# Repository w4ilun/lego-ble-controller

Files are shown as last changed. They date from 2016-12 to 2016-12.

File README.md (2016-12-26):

##4-channel Bluetooth LE controller for Lego Power Functions w/ Web Bluetooth

First attempt at making a Lego BLE contoller.

* PCB Design and Fabrication - EasyEDA
* Firmware - Arduino
* Remote Control App - Web Bluetooth APIs

###Top Layer
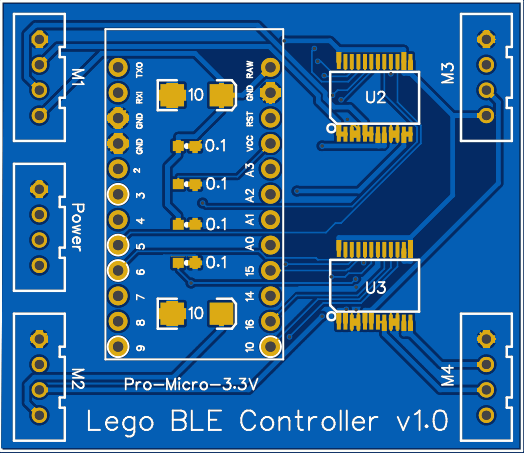
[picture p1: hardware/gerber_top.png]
Top Layer


###Bottom Layer
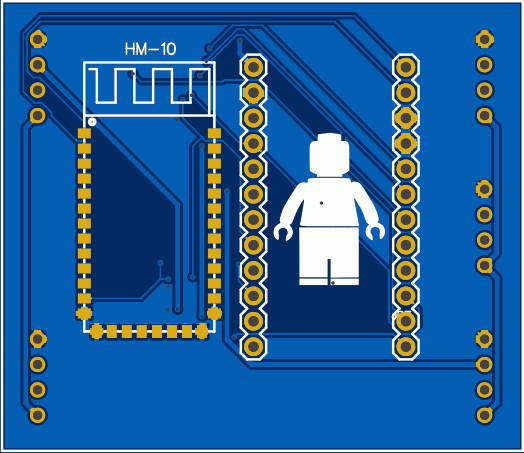
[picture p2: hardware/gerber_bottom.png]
Bottom Layer


###Components
* 1 x Arduino Pro Micro module
* 1 x HM-10 Bluetooth LE module
* 2 x TB6612FNG Motor Controller IC - U2 & U3
* 2 x Tantalum Capacitor 10uF 25V
* 4 x Ceramic Capacitor 0.1uF 25V
* 5 x JST-XH 4 Pin Connectors Male/Female pairs
* 5 x Lego Power Functions Extension Wire

###Remote Control App
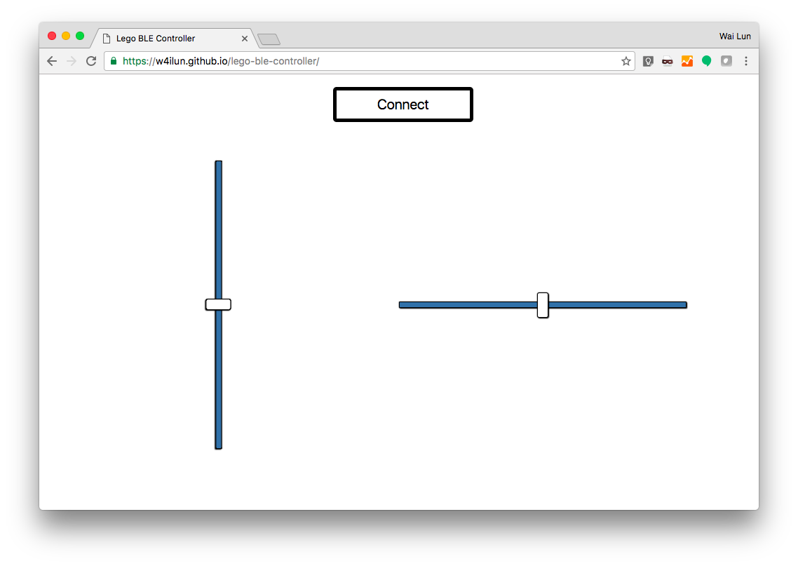
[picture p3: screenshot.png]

* Uses the Web Bluetooth API in Chrome to connect and control the board
* To use, first enable Web Bluetooth in your Chrome browser (e.g. chrome://flags )
* Go to https://w4ilun.github.io/lego-ble-controller on your phone or desktop and click connect
* Feel free to customize the UI with additional controls and adding the remaining channels

##Control Protocol
* The acceptable range for each channel are integers between -255 and 255
* (-) negative values will reverse the motor/servo direction
* Encoding Scheme: **m1val**#**m2val**#**m3val**#**m4val** E.g. 100#255#-128#30

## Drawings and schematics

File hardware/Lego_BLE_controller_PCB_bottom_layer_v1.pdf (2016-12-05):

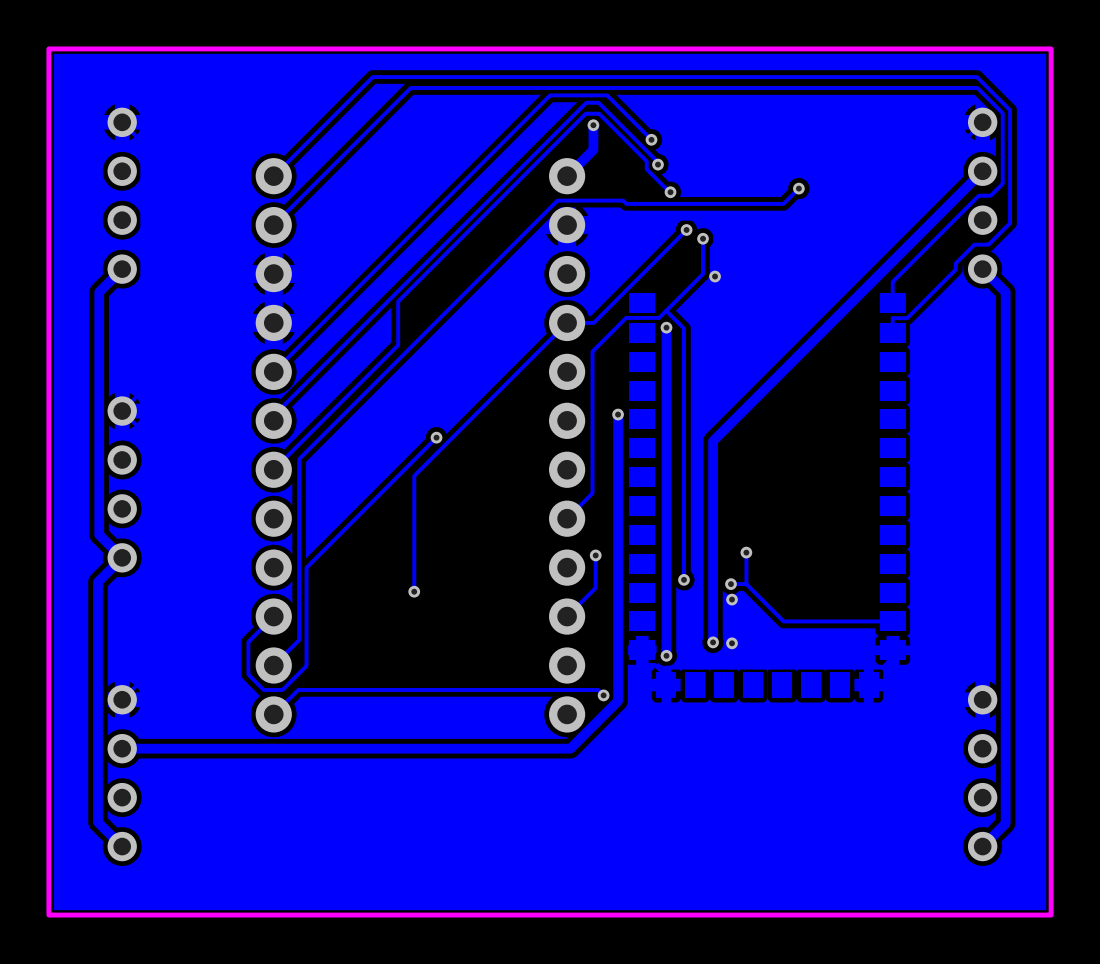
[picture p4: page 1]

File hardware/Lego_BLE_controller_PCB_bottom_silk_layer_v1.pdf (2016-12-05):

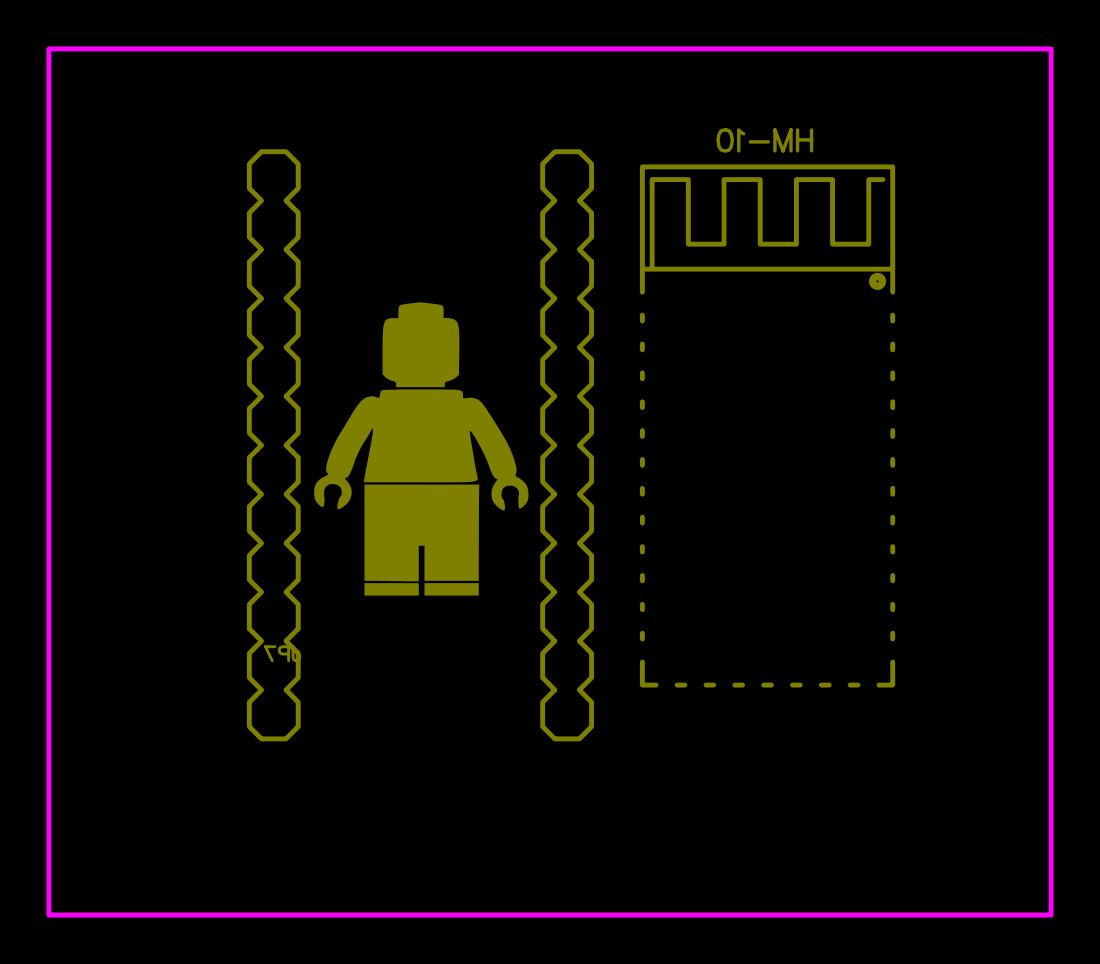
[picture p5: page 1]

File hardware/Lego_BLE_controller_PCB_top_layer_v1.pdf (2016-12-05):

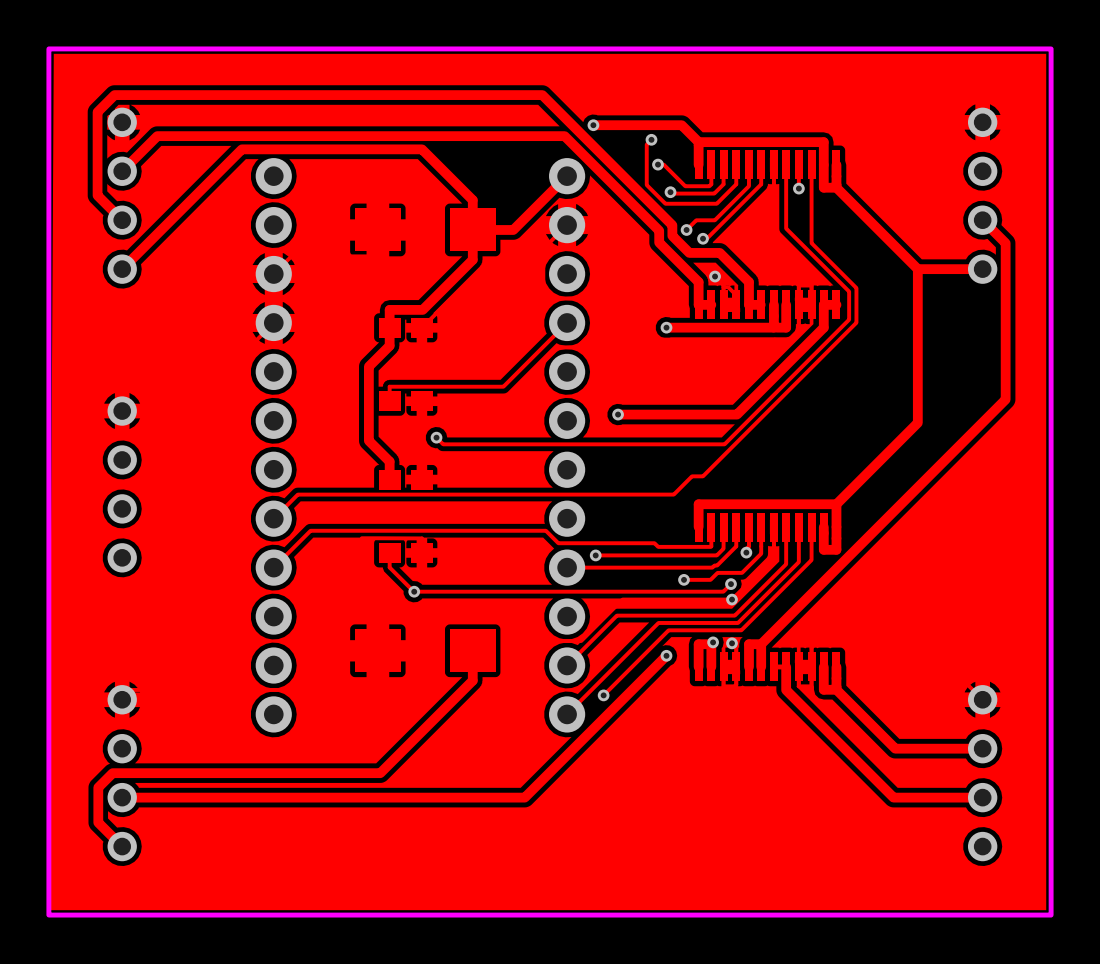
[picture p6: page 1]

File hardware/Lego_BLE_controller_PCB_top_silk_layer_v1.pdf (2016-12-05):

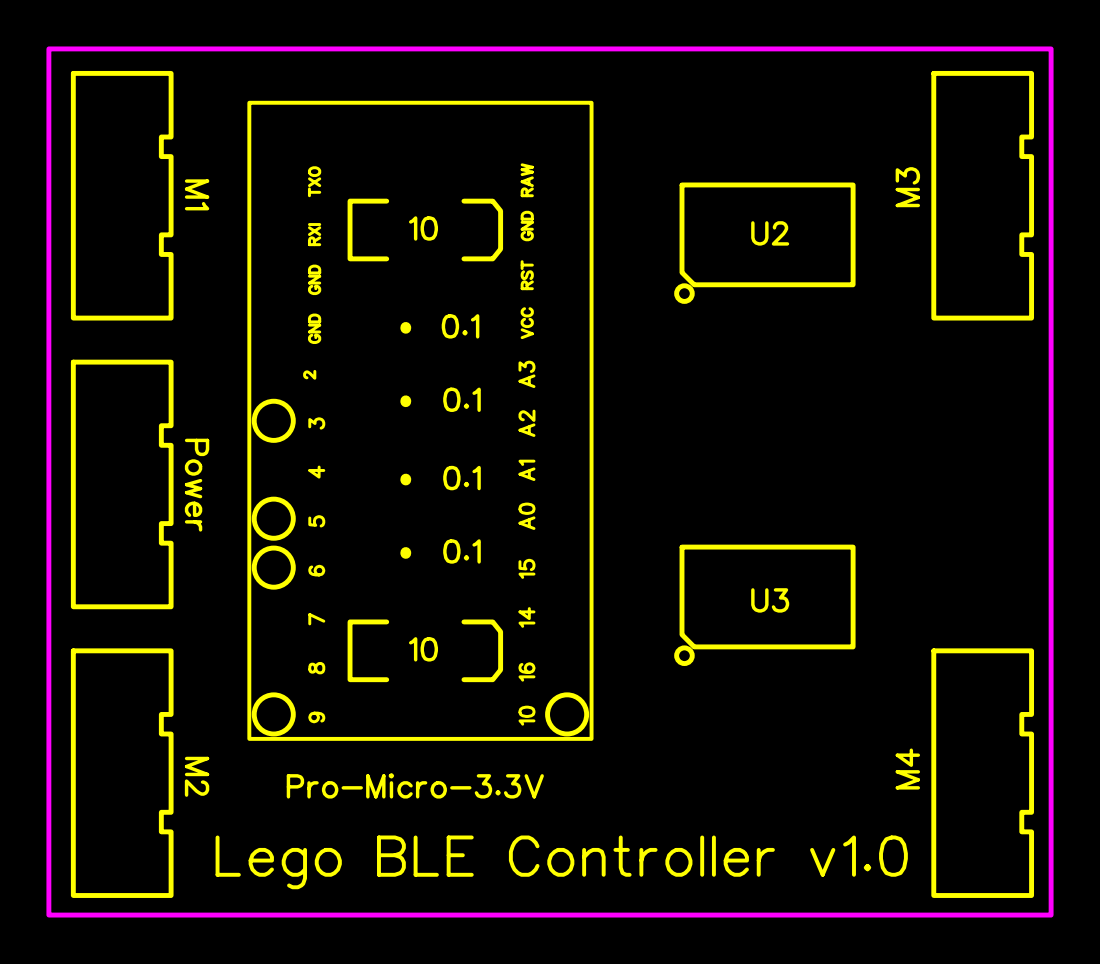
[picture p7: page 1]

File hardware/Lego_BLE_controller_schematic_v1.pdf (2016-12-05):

## VCC

V3.3

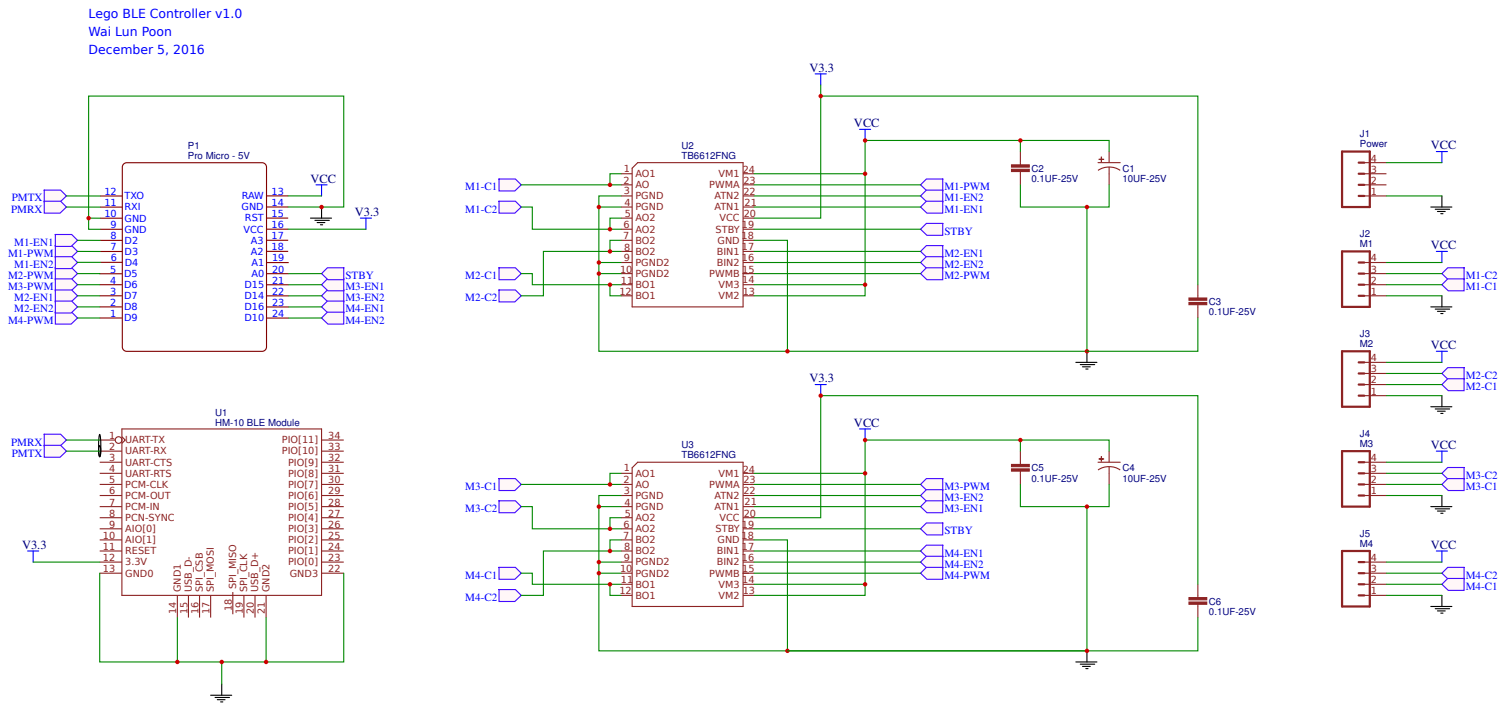
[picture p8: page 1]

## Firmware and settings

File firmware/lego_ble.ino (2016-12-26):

#define INPUT_SIZE 30 //input buffer size

//motor channel struct
struct Channel {
    int en1;
    int en2;
    int pwm;
    int value;
};

Channel m1 = { 2 , 4 , 3 , 0 }; // en1 , en2 , pwm , value
Channel m2 = { 7 , 8 , 5 , 0 };
Channel m3 = { 15 , 14 , 6 , 0 };
Channel m4 = { 16 , 10 , 9 , 0 };

//standby, pin must be HIGH to enable motor drivers
int standby = 18;

//serial input buffer
char inputBuffer[INPUT_SIZE + 1];

void setup() {
    
    pinMode(m1.en1, OUTPUT);
    pinMode(m1.en2, OUTPUT);
    pinMode(m1.pwm, OUTPUT);
    pinMode(m2.en1, OUTPUT);
    pinMode(m2.en2, OUTPUT);
    pinMode(m2.pwm, OUTPUT);
    pinMode(m3.en1, OUTPUT);
    pinMode(m3.en2, OUTPUT);
    pinMode(m3.pwm, OUTPUT);
    pinMode(m4.en1, OUTPUT);
    pinMode(m4.en2, OUTPUT);
    pinMode(m4.pwm, OUTPUT);
    pinMode(standby, OUTPUT);

    digitalWrite(standby, HIGH);

    Serial1.begin(115200); //hardware Serial1 - default HM-10 baud rate is 9600, mine was changed e.g. AT+BAUD
    Serial1.setTimeout(10);
    while(!Serial1);
}

void loop() {
    if(Serial1.available() > 0){
        byte size = Serial1.readBytes(inputBuffer, INPUT_SIZE);
        Serial.println(inputBuffer); //print input for debugging
        inputBuffer[size] = 0; //null terminate input
        
        //tokenize input commands with '#' as the deliminator
        char* command = strtok(inputBuffer, "#");
        m1.value = atoi(command);
        command = strtok(0, "#");
        m2.value = atoi(command);
        command = strtok(0, "#");
        m3.value = atoi(command);
        command = strtok(0, "#");
        m4.value = atoi(command);
        updatePWM();

        //print parsed values
        Serial.print("M1 Speed is ");
        Serial.println(m1.value);
        Serial.print("M2 Speed is ");
        Serial.println(m2.value);
        Serial.print("M3 Speed is ");
        Serial.println(m3.value);
        Serial.print("M4 Speed is ");
        Serial.println(m4.value);             
    }
}

void updatePWM(){
    //Channel 1
    if(m1.value < 0){
        digitalWrite(m1.en1, LOW);
        digitalWrite(m1.en2, HIGH);
    }else{
        digitalWrite(m1.en1, HIGH);
        digitalWrite(m1.en2, LOW);   
    }
    analogWrite(m1.pwm, abs(m1.value));
    //Channel 2
    if(m2.value < 0){
        digitalWrite(m2.en1, LOW);
        digitalWrite(m2.en2, HIGH);
    }else{
        digitalWrite(m2.en1, HIGH);
        digitalWrite(m2.en2, LOW);   
    }
    analogWrite(m2.pwm, abs(m2.value));
    //Channel 3
    if(m3.value < 0){
        digitalWrite(m3.en1, LOW);
        digitalWrite(m3.en2, HIGH);
    }else{
        digitalWrite(m3.en1, HIGH);
        digitalWrite(m3.en2, LOW);   
    }
    analogWrite(m3.pwm, abs(m3.value));
    //Channel 4
    if(m4.value < 0){
        digitalWrite(m4.en1, LOW);
        digitalWrite(m4.en2, HIGH);
    }else{
        digitalWrite(m4.en1, HIGH);
        digitalWrite(m4.en2, LOW);   
    }
    analogWrite(m4.pwm, abs(m4.value));
}

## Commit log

2016-12-05 added Gerber files
    [Gerber_drill.GBL, Gerber_drill.GBO, Gerber_drill.GBP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]
2016-12-24 added arduino firmware
2016-12-26 button styles
